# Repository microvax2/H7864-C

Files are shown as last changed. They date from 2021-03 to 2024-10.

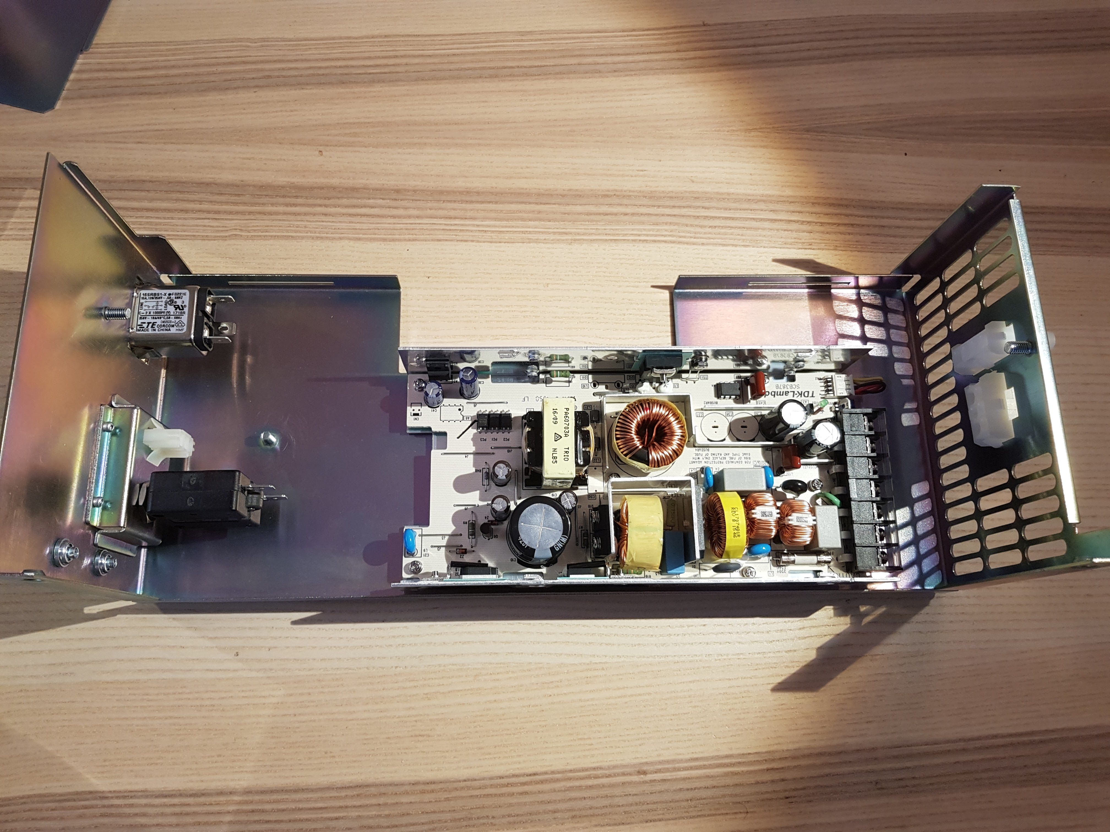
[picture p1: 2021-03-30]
Photos and Documents/H7864-C Before Wiring [1].jpg

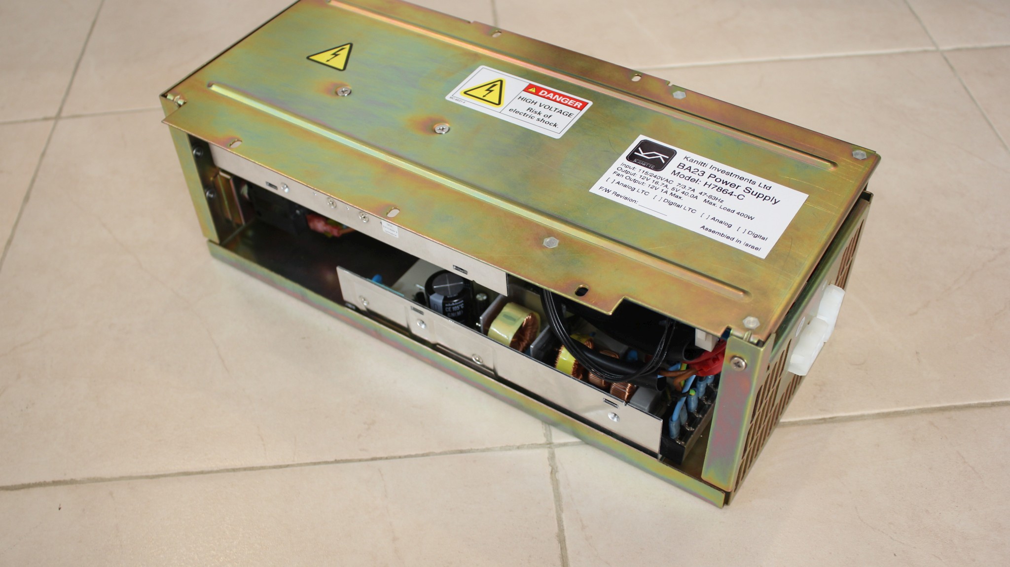
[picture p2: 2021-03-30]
Photos and Documents/H7864-C Assembled.jpg

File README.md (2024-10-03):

# H7864-C
A modern replacement for DEC's H7864-A/H7864-B (Astec AA12131)

Non-commercial license to do anything you want with the stuff in this repository.
For commecial licensing please contact me.

Project Folders:
Software - PIC12F675 firmware and sources

Metal Parts

Looms

PCB

Assembly

**IMPORTANT**

There are three "blocks" marked on the power supply control PCB.

A. A 74AC14 TTL gate - to generate POK, DCOK signals on power-up

B. An analog line monitoring circuitry that feeds the PIC microcontroller with a square wave signal and generates a "True" LTC clock

C. A PIC microcontroller - to generate POK, DCOK signals on power-up and an artificial LTC clock

Blocks A and C are mutually exclusive

Block B, if assembled together with Block C, enables the PIC to generate a correct sequence for POK, DCOK upon power-off.

**IMPORTANT** If assembling Block C (microcontroller) - don't populate the 74AC14 (U1).

Why this is important: ONLY OPTION B + C WILL PRESERVE THE TOY (Time of Year) CLOCK OF THE KA630.
This would probably be true for other KA6xx CPU Boards that keep time, boot parameters etc in battery-backed RAM.
The reason being, correct hardware shutdown must be performed by the CPU board upon power-off detection.

So your assembly options are:

**Option C: if you are lazy and don't care about preserving TOY clock after power-off, or have a PDP-11 and need an artificial LTC clock signal**

**Option A: if you are lazy, don't need an LTC clock, and don't even want to use a microcontroller**

**Option A+B: if you are lazy, have a PDP-11 system, and need a working, real LTC clock fed from mains**

**Option B+C: if you are lazy and want to keep the TOY clock functioning when power is removed**

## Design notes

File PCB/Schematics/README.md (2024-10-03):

Schematics for H7864-C

** READ THE COMMENTS ON SCHEMATIC SHEET 2 **
** ASSEMBLE ONLY ACCORDING TO THE OPTIONS YOU WANT **

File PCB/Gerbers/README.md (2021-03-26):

Gerber files for REV B PCB manufacturing

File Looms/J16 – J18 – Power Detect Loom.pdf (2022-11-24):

## J16 – J18 – Power Detect Loom

TE 52935 | TE 52935

120mm
AWG16-20

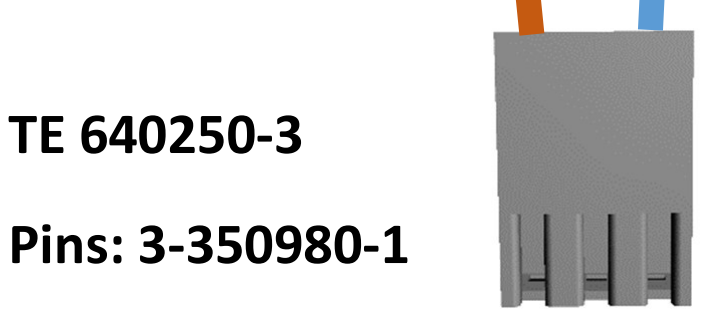
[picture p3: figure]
Pins: 3-350980-1

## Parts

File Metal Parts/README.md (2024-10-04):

Metalworks production files

**Important**
The files show a design plus two modifications (three holes moved and power entry cutout changed).
Make sure you account for those modifications.

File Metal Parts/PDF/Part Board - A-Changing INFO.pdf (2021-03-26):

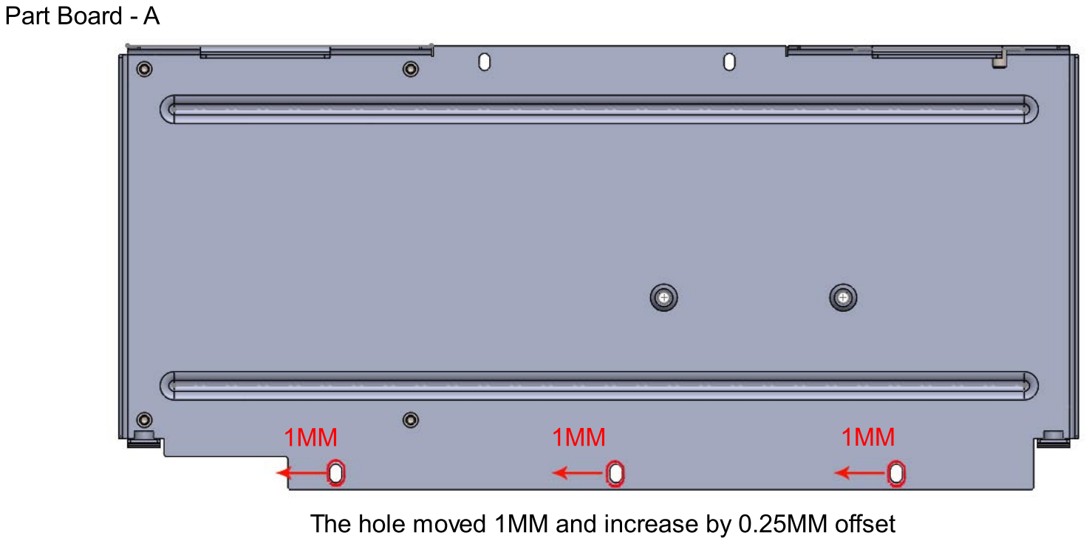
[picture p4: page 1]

Theholemoved1MMandincreaseby0.25MMoffset

PartBoard-A

1MM | 1MM | 1MM

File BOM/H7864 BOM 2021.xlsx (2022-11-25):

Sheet: Part List Report
 | Component list |  | Bill of Materials for PCB Document [H7864-B.pcbdoc]
 | Source Data From: |  | H7864-B.pcbdoc
 | Project: |  | H7864.PrjPcb
 | Variant: |  | Consult Schematic Sheet 2
 | Report Date: | 28/03/21 | 15:38
 | Print Date: | 2022-11-25 | 13:55:00
# | Designator | P/N | Description | Variant(S) (Consult Schematic Sheet 2) | Comment | Quantity
1 | C1 | TAJS106K006RNJ |  | A | 10uF | 1
2 | C2 | VJ0805Y103JXQPW1BC | Capacitor |  | VJ0805Y103JXAPW1BC | 1
3 | C3 | TCTAS0J107M8R |  | A | 100uF | 1
4 | C4 | B32642B6473J | Capacitor | B | 47nF 400VAC 15mm FILM | 1
5 | C5 | VJ0805Y104KXQCW1BC | Capacitor | C | VJ0805Y103JXAPW1BC | 1
6 | D1 | BAT54C | Schottky Barrier Double Diode | A | BAT54C | 1
7 | D2 | 1N4007 | 1 Amp General Purpose Rectifier |  | 1N4007 | 1
8 | D3 | 1N4007 | 1 Amp General Purpose Rectifier | B | 1N4007 | 1
9 | D4 | 1N4007 | 1 Amp General Purpose Rectifier |  | 1N4007 | 1
10 | D5 | SB130-T | 1 Amp General Purpose Rectifier |  | SB130-T | 1
11 | D6 | 1N4007 | 1 Amp General Purpose Rectifier | B | 1N4007 | 1
12 | D7 | BAT54C | Schottky Barrier Double Diode | C | BAT54C | 1
13 | F1 | 65600001009 | Fuse Holder 65600001009 + cover 65900000009 | B | Fuse holder, use 63mA fuse P/N 5ST 63-R | 1
14 | J9 | 640385-9 |  |  | 1-640385-9 | 1
15 | J14 | 640385-9 |  |  | 1-640385-9 | 1
16 | J15 | 640385-9 |  |  | 1-640385-9 | 1
17 | J16 | TE 640445-3 see note | Socket |  | Wire Solder | 1
18 | J17 |  | Socket |  | Remote On Off - | 1
19 | J18 | TE 640445-3 see note | Socket |  | Wire Solder | 1
20 | J19 | 640388-2 | Socket |  | Remote On Off + | 1
21 | LED1 | LTST-C170KRKT |  |  | LTST-C170KRKT | 1
22 | LED2 | LTST-C170KRKT |  |  | LTST-C170KRKT | 1
23 | LED3 | LTST-C170KRKT |  |  | LTST-C170TGKT | 1
24 | LED4 | LTST-C170KRKT |  |  | LTST-C170TGKT | 1
25 | MOV1 | 471KD10 | 10mm Disc Varistor | B | V10E300P, MOV-10D471K | 1
26 | P2 | 61300211121 | Header, 2-pin |  | Header/Jumper | 1
27 | P3 | B8B-PHDSS(LF)(SN) |  |  | B8B-PHDSS(LF)(SN) | 1
28 | P4 | 61300211121 | Header, 2-pin |  | Header/Jumper | 1
29 | P5 | B8B-PHDSS(LF)(SN) |  |  | B8B-PHDSS(LF)(SN) | 1
30 | P6 | 61300211121 | Header, 2-pin |  | Header/Jumper | 1
31 | P8 | 61300211121 | Header, 2-pin | C | Header/Jumper | 1
32 | Q1 | SI2306BDS-T1-E3 | N-Channel MOSFET |  | SI2306BDS-T1-E3 | 1
33 | Q2 | SI2306BDS-T1-E3 | N-Channel MOSFET |  | SI2306BDS-T1-E3 | 1
34 | Q3 | SI2306BDS-T1-E3 | N-Channel MOSFET |  | SI2306BDS-T1-E3 | 1
35 | R1 | CRCW080526K1FKEA | Resistor | A | 26.1K 1% | 1
36 | R2 | CRCW08051K00FKEAC | Resistor |  | 1K | 1
37 | R3 | CRCW0805180KFKEAC | Resistor | A | 180K 1% | 1
38 | R4 | CRCW080510K0JNEAC | Resistor | A | 10K | 1
39 | R5 | CRCW08051K00FKEAC | Resistor |  | 1K | 1
40 | R6 | CRCW0805180KFKEAC | Resistor | A | 180K 1% | 1
41 | R7 | CRCW0805330RFKEB | Resistor |  | 330 | 1
42 | R8 | MOS1CT528R223J | Resistor | B | 22K 1W TH | 1
43 | R9 | CRCW0805330RFKEB | Resistor |  | 330 | 1
44 | R10 | CRCW0805178RFKEA | Resistor |  | 178 | 1
45 | R11 | MOS1CT528R223J | Resistor | B | 22K 1W TH | 1
46 | R12 | CRCW080510K0JNEAC | Resistor | B | 10K | 1
47 | R13 | CRCW08050000Z0EC | Resistor |  | 0 | 1
48 | R14 | CRCW08052K00FKEAHP | Resistor |  | 2K | 1
49 | R15 | CRCW0805330RFKEB | Resistor |  | 330 | 1
50 | R16 | CRCW08050000Z0EC | Resistor |  | 0 | 1
51 | R17 | CRCW08051K00FKEAC | Resistor |  | 1K | 1
52 | R18 | CRCW0805383RFKEA | Resistor |  | 383 | 1
53 | R19 | CRCW08051K00FKEAC | Resistor |  | 1K | 1
54 | U1 | SN74HC14N | Hex Schmitt-Trigger Inverter | A, B | SN74AC14 | 1
55 | U2 | LTV816 | 4-Pin Phototransistor Optocoupler | B | LTV816 | 1
56 | U3 |  | FLASH-Based 8-Bit CMOS Microcontroller, 10-Bit A/D, 8-Pin PDIP, Industrial Temperature | C | PIC12F675-I/P | 1
Approved |  |  | Notes |  |  | 56
Note: J16-J18 can be populated with TE 640445-3, center pin must be removed. Orientation should match the wiring of loom J16-J18 for Live/Neutral connectios

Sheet: Project Information
Project Full Path | D:\GoogleDrive\VAX Museum\H7864\PCB Rev B\H7864.PrjPcb
Project Filename | H7864.PrjPcb
Variant Name | None
Data-Source Filename | H7864-B.pcbdoc
Data-Source Full Path | D:\GoogleDrive\VAX Museum\H7864\PCB Rev B\H7864-B.pcbdoc
Title | Bill of Materials for PCB Document [H7864-B.pcbdoc]
Total Quantity | 57
Report Time | 15:38
Report Date | 28/03/21
Report Date & Tine | 28/03/21 15:38
Output Name | Bill of Materials
Output Type | BOM_PartType
Output Generator Name | BOM
Output Generator Description | Bill of Materials

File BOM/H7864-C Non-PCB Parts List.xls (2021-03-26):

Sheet: Part List Report
 | Non-PCB Parts List
 | Source Data From:
 | Project: | H7864-C
 | Variant: | All Variants
 | Report Date:
 | Print Date:
# | Designator | Description | Supplier | Supplier p/n | Qty | Comment
1 | Metal Enclosure |  |  |  | 1
2 | Fan Cord | Qualtek 07145-24 | Mouser | 562-07145-24 | 1
5 | IEC Socket | TE Connectivity 15SRB1-Z | Mouser | 592-15SRB1-Z | 1
6 | Overload Switch- 5A | TE 1-1423364-2 | Mouser | 655-W57-XB1A4A10-5 | 1
7 | Overload Switch- 10A | TE 1-1423364-4 | Mouser | 655-1-1423364-4 (https://www.mouser.co.il/ProductDetail/TE-Connectivity-PB/1-1423364-4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) | 1
8 | Cable Tie | Cable tie, 100x2.5mm |  |  | 1
9 | LOOM1: Power |  |  |  | 7
10 | LOOM2: 5V + | 14AWG Red Solder to Fork 140mm | 76812.R8.03 (https://www.digikey.com/product-detail/en/general-cable-carol-brand/76812.R8.03/C76812R-50-ND/5452559) |  | 2
11 | LOOM3: 5V GND | 14AWG Black Solder to Fork 140mm | 76812.R8.01 |  | 2
12 | LOOM4: 12V + | 14AWG Red Solder to Fork 140mm | 76812.R8.03 (https://www.digikey.com/product-detail/en/general-cable-carol-brand/76812.R8.03/C76812R-50-ND/5452559) |  | 2
13 | LOOM5: 12V GND | 14AWG Black Solder to Fork 140mm | 76812.R8.01 |  | 2
14 | LOOM6: FRONT FAN |  |  |  | 1
15 | LOOM7: REMOTE |  |  |  | 1
16 | LOOM8: P/S | Hosuing + Jumper Pre-Crimped + Housing |  |  | 2
16 | LOOM8: Front PW | Hosuing + Jumper Pre-Crimped + Housing |  |  | 2
 | FAN | Modern replacement fan is Orion OD1238-12HTB |  | OD1238-12HTB

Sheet: Project Information
Project Full Path | W:\DIFT2\PCB Rev A\DIFT2.PrjPcb
Project Filename | DIFT2.PrjPcb
Variant Name | None
Data-Source Filename | DIFT2.PrjPcb
Data-Source Full Path | W:\DIFT2\PCB Rev A\DIFT2.PrjPcb
Title | <Parameter Title not found>
Total Quantity | 34
Report Time | 17:41:05
Report Date | 19/05/11
Report Date & Tine | 19/05/11 17:41:05
Output Name | Bill of Materials
Output Type | BOM_PartType
Output Generator Name | BOM
Output Generator Description | Bill of Materials

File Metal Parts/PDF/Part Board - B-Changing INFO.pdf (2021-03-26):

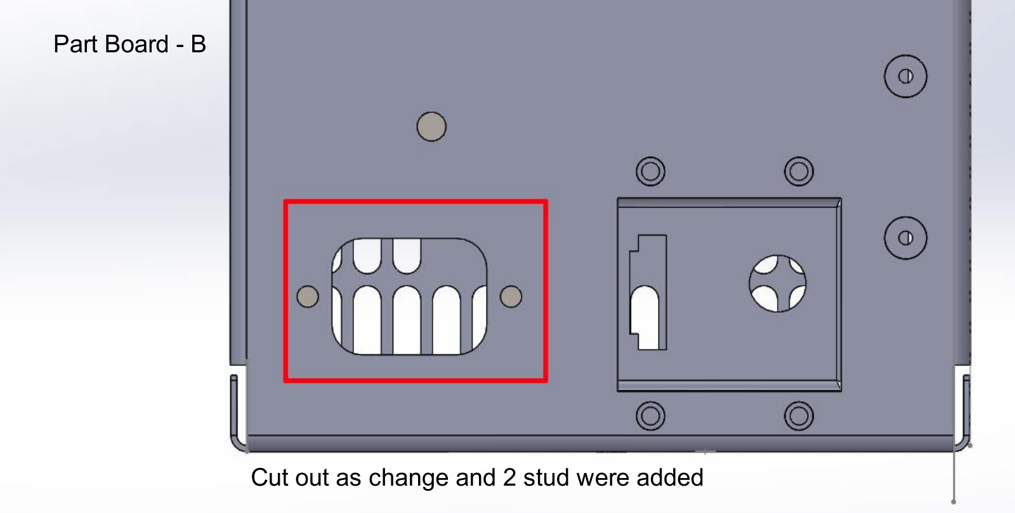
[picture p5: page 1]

PartBoard-B

Cutoutaschangeand2studwereadded

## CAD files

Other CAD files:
Metal Parts/XT/SB-20-7-17.x_t
Metal Parts/XT/SB.x_t
Metal Parts/XT/SUB Assem board A-18.09.17.x_t
Metal Parts/XT/SUB Assem board B-18.09.17.x_t

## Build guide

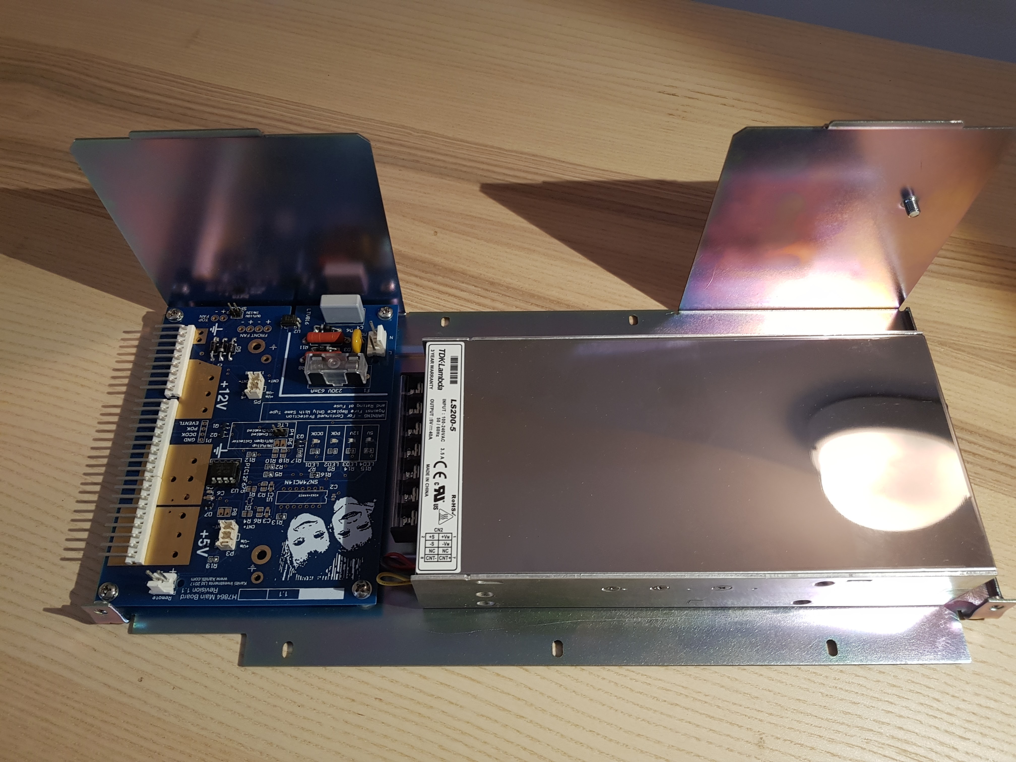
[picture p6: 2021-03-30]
Photos and Documents/H7864-C Before Wiring [2].jpg

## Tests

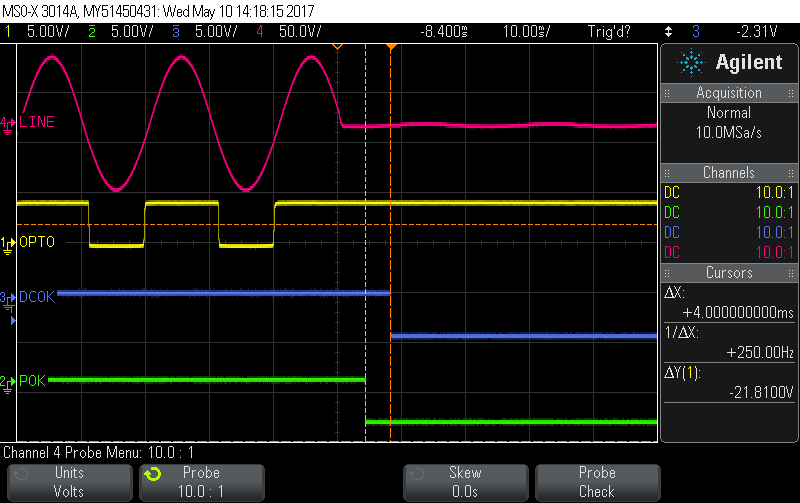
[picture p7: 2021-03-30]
Software Test Results/50HZEXP5 2017-05-10 09-41-35.png

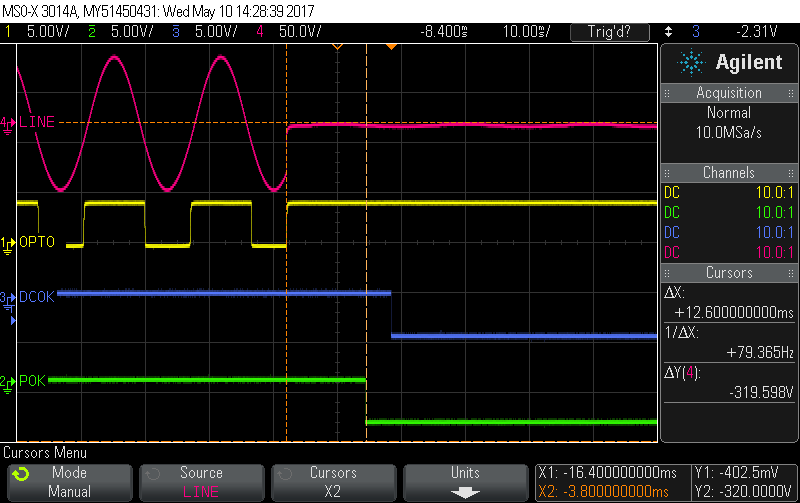
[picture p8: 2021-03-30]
Software Test Results/60HZEXP4 2017-05-10 09-51-53.png

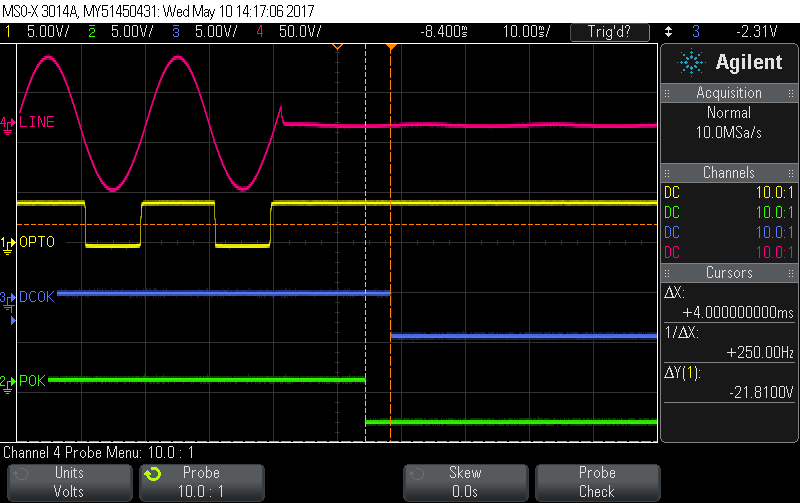
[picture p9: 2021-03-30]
Software Test Results/50HZEXP4 2017-05-10 09-40-23.png

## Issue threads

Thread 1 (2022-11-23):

Varistor alternative as well as part no. of mains connector

EarwainBanadar, 2022-11-23:
1. The varistor TVB7S471KR seems not to available anymore. Could you suggest and alternative?
     Not to forget that the TVB7S471KR is a SMD, not a disc type varistor.
3. The connector in the mains section in parallel to the varistor is not listed in the BOM. Of which partnumber is this connector?

microvax2, 2022-11-24:
1. Alternative varistors added to BOM: V10E300P, MOV-10D471K. Note that any 10mm 470V disc varistor will fit OK.
2. J16-J18 Part number added to BOM: TE 640446-3 with center pin removed
3. Added Loom "J16-J18 Power Detect", spade connectors on one side and TE 640250-3 on the other side, center pin unpopulated, two pins are 3-350980-1
4. Modified main AC wiring schematic to show connection of "J16-J18 Power Detect Loom", from live/neutral to main PCB.

EarwainBanadar, 2022-11-25:
I think there is a wrong PartNo. for item 54 in the PCB BOM.

SN74AHCT14D is a SMD type, would be SN74AC14N the correct one?

Closed 2023-01-06.

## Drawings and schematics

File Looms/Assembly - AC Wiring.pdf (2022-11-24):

LS200-5

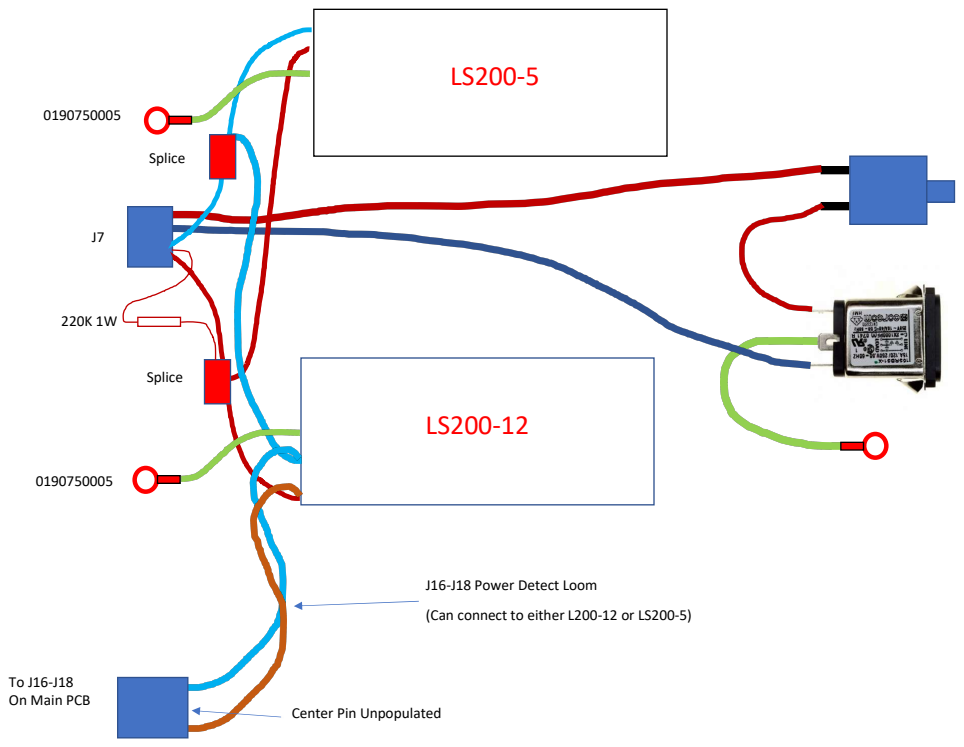
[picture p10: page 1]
Splice

J16-J18 Power Detect Loom
(Can connect to either L200-12 or LS200-5)

On Main PCB

Center Pin Unpopulated

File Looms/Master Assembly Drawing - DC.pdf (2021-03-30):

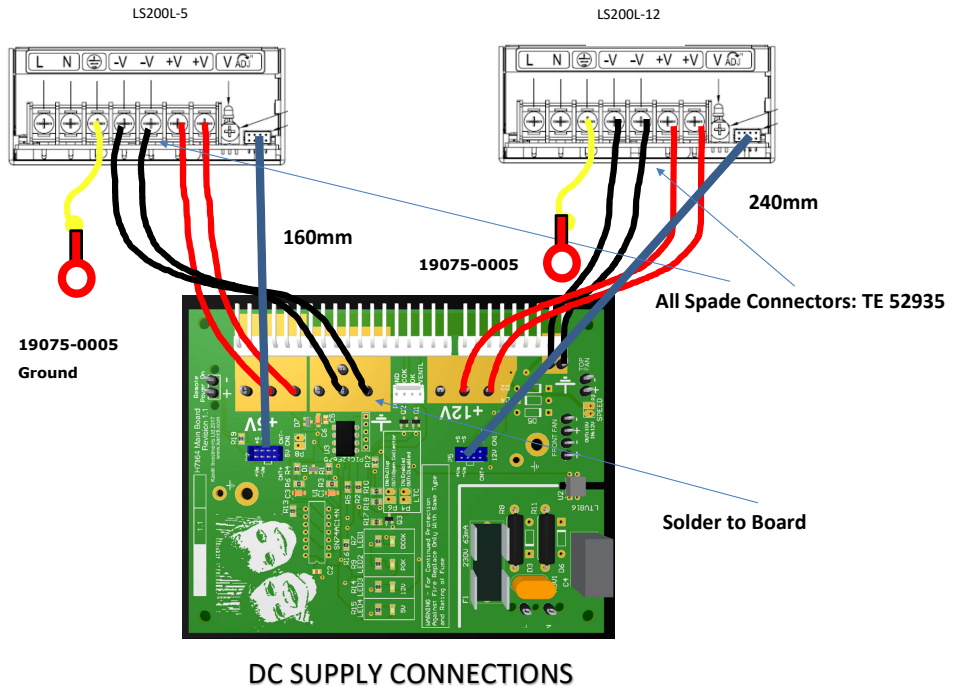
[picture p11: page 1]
Ground

All Spade Connectors: TE 52935

Solder to Board

DC SUPPLY CONNECTIONS

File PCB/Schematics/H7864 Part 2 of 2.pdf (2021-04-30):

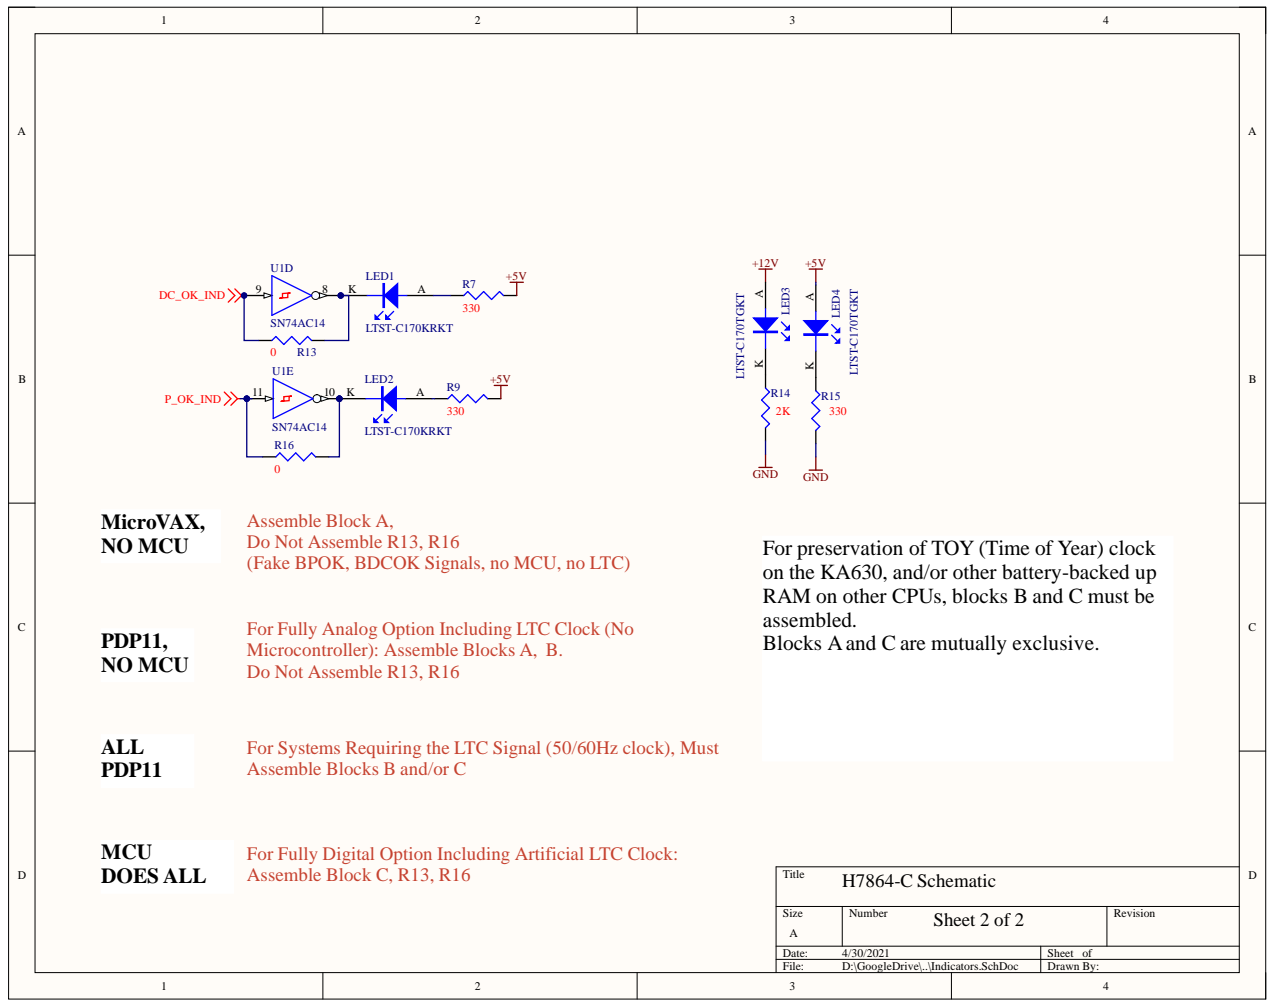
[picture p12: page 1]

Assemble Block A,
Do Not Assemble R1
(Fake BPOK, BDCOK Sig

For preservation of TOY (Time of
on the KA630, and/or other battery-backed up
RAM on other CPUs, blocks B and C must be
assembl
Blocks

A and C are mutually exclusive.

For Fully Digital Optio
Assemble Block C, R1

Size A | Nu m b er Sheet 2 of 2 | Revisio n

Date: 4/3 0/2 0 2 1 | Sheet o f
File: D:\Go o gleDrive\..\I n dicato rs.SchDo c | Drawn B y :

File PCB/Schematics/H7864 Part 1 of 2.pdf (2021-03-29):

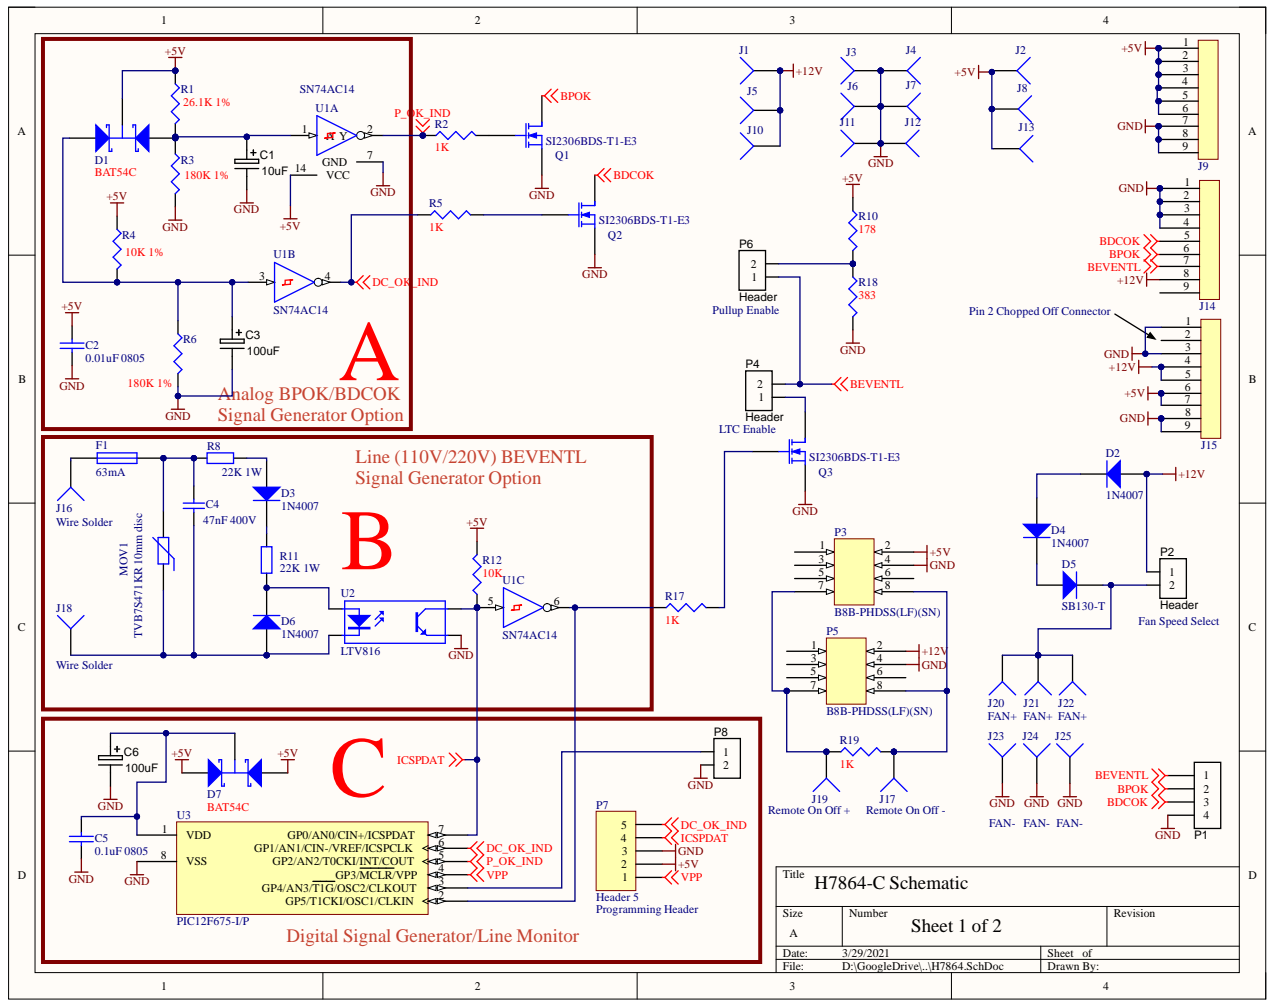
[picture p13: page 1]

Pin 2 Chopped Off Connector

Size A | Number Sheet 1 of 2 | Revision

Digital Signal Generator/Line Monitor

Date: 3/29/2021 | Sheet of
File: D:\GoogleDrive\..\H7864.SchDoc | Drawn By:

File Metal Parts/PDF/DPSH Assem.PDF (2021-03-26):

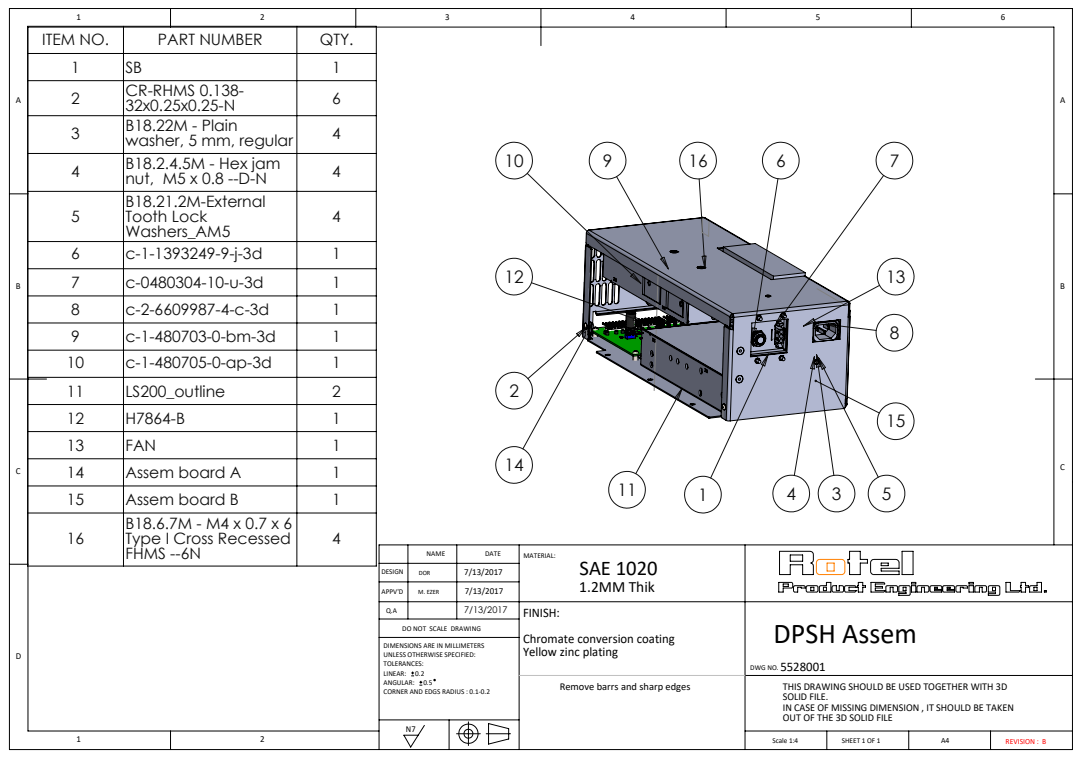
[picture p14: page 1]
SAE 1020 1.2MM Thik; REVISION : B; DPSH Assem; Scale 1:4; SHEET 1 OF 1; M. EZER

ITEM NO. | PART NUMBER | QTY.
1 | SB | 1
2 | CR-RHMS 0.138-32x0.25x0.25-N | 6
3 | B18.22M - Plain washer, 5 mm, regular | 4
4 | B18.2.4.5M - Hex jam nut, M5 x 0.8 --D-N | 4
5 | B18.21.2M-External Tooth Lock Washers_AM5 | 4

6 | c-1-1393249-9-j-3d | 1
7 | c-0480304-10-u-3d | 1
8 | c-2-6609987-4-c-3d | 1
9 | c-1-480703-0-bm-3d | 1
10 | c-1-480705-0-ap-3d | 1
11 | LS200_outline | 2
12 | H7864-B | 1
13 | FAN | 1
14 | Assem board A | 1
15 | Assem board B | 1
16 | B18.6.7M - M4 x 0.7 x 6 Type I Cross Recessed FHMS --6N | 4

DO NOT SCALE DRAWING
DIMENSIONS ARE IN MILLIMETERS
UNLESS OTHERWISE SPECIFIED:
TOLERANCES:
LINEAR: 0.2
ANGULAR: 0.5
CORNER AND EDGS RADIUS : 0.1-0.2

FINISH:
Chromate conversion coating
Yellow zinc plating

DWG NO. 5528001
THIS DRAWING SHOULD BE USED TOGETHER WITH 3D
SOLID FILE.
IN CASE OF MISSING DIMENSION , IT SHOULD BE TAKEN
OUT OF THE 3D SOLID FILE

Remove barrs and sharp edges

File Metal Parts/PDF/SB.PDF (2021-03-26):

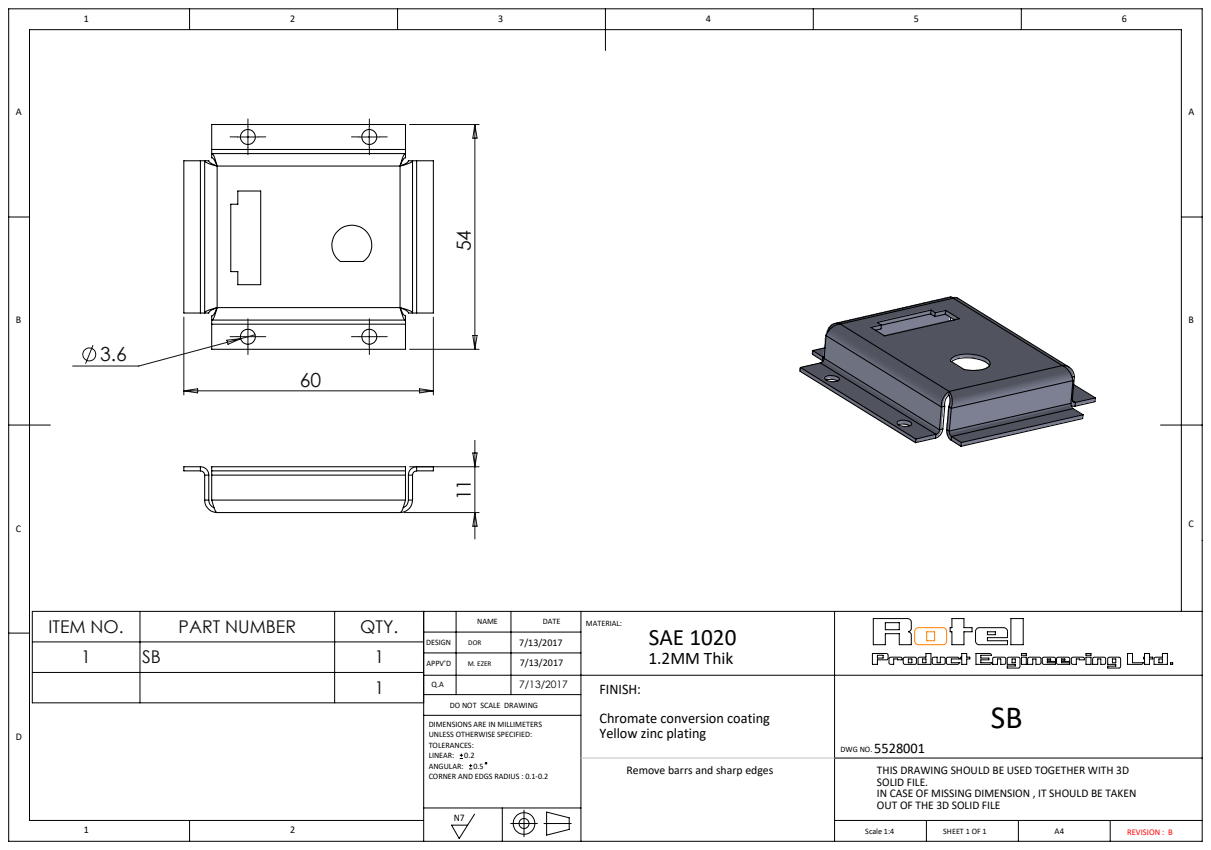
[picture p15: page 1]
REVISION : B; Scale 1:4; SHEET 1 OF 1; M. EZER

ITEM NO. | PART NUMBER | QTY.
1 | SB | 1

SAE 1020
1.2MM Thik
FINISH:
Chromate conversion coating
Yellow zinc plating

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

SB DWG NO. 5528001

Remove barrs and sharp edges

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

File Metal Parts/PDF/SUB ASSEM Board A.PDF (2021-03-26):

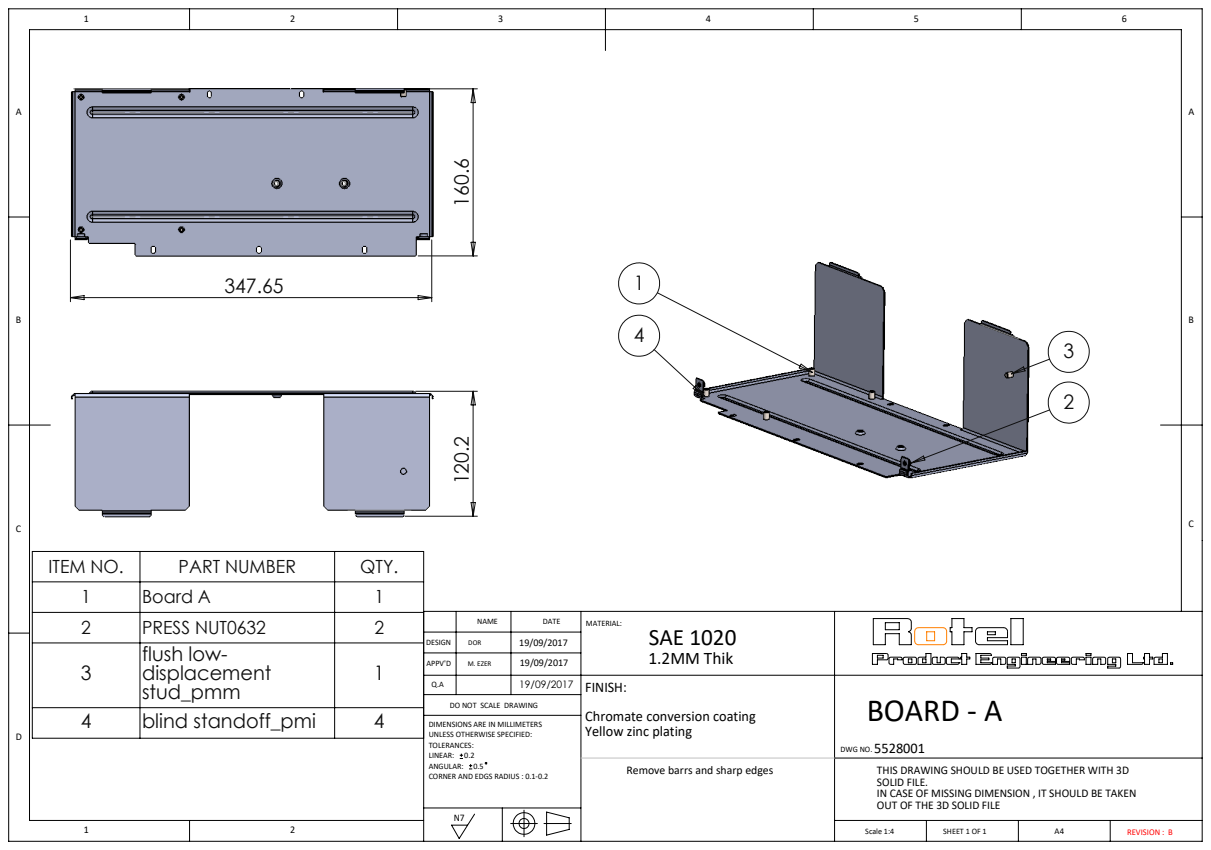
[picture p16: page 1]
SAE 1020 1.2MM Thik; REVISION : B; BOARD - A; Scale 1:4; SHEET 1 OF 1; M. EZER

ITEM NO. | PART NUMBER | QTY.
1 | Board A | 1
2 | PRESS NUT0632 | 2
3 | flush low-displacement stud_pmm | 1

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

FINISH:
Chromate conversion coating
Yellow zinc plating

4 | blind standoff_pmi | 4

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

Remove barrs and sharp edges

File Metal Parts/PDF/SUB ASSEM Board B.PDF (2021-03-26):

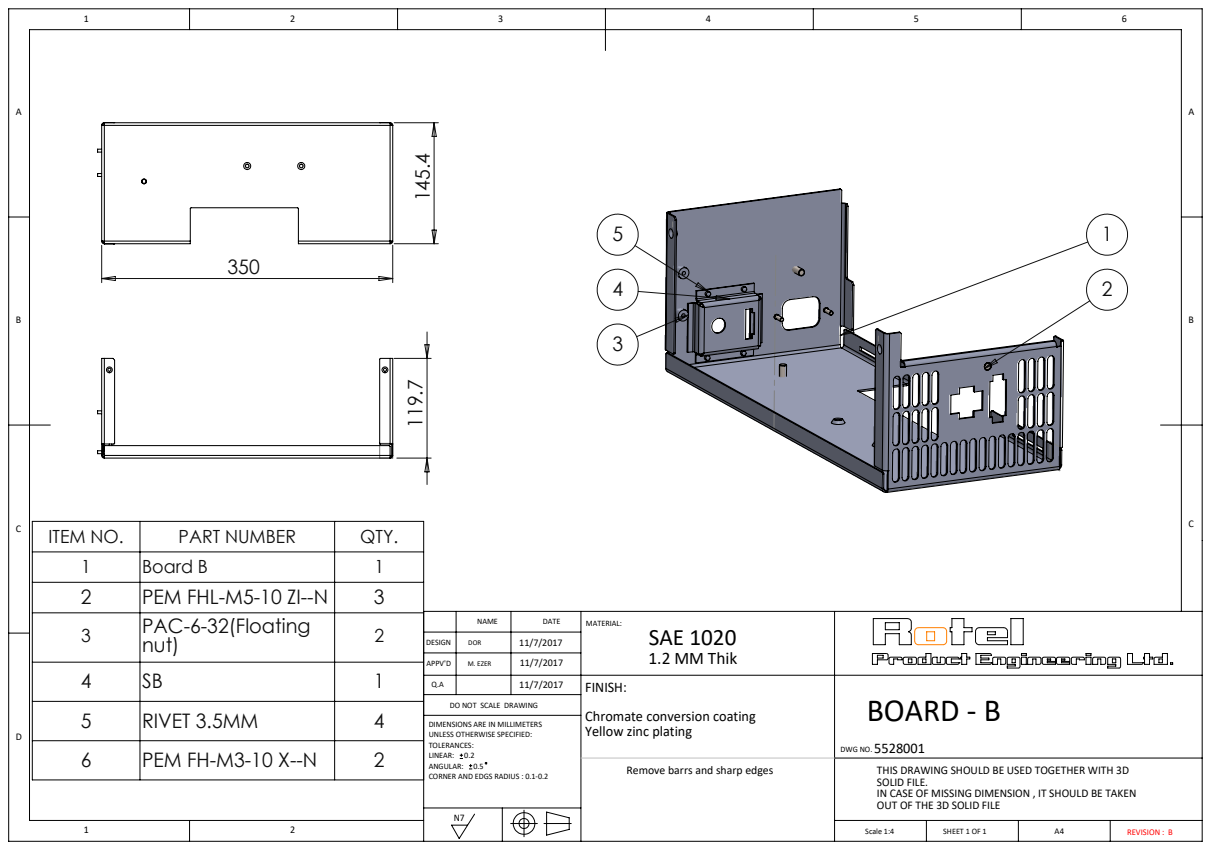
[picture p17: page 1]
SAE 1020 1.2 MM Thik; REVISION : B; BOARD - B; Scale 1:4; SHEET 1 OF 1; M. EZER

ITEM NO. | PART NUMBER | QTY.
1 | Board B | 1
2 | PEM FHL-M5-10 ZI--N | 3
3 | PAC-6-32(Floating nut) | 2

4 | SB | 1
5 | RIVET 3.5MM | 4
6 | PEM FH-M3-10 X--N | 2

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

FINISH:
Chromate conversion coating
Yellow zinc plating

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

Remove barrs and sharp edges

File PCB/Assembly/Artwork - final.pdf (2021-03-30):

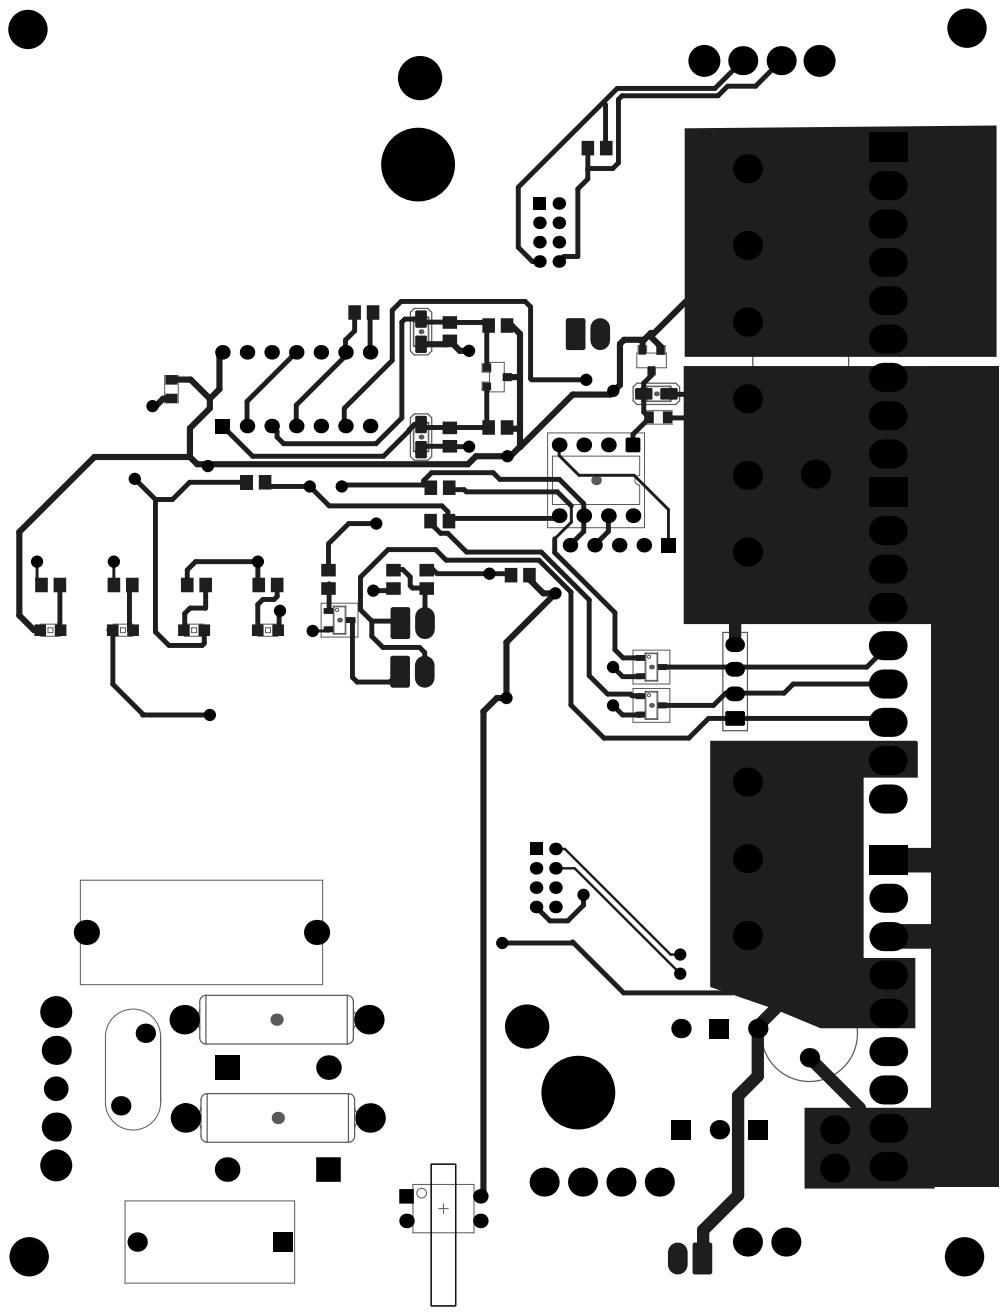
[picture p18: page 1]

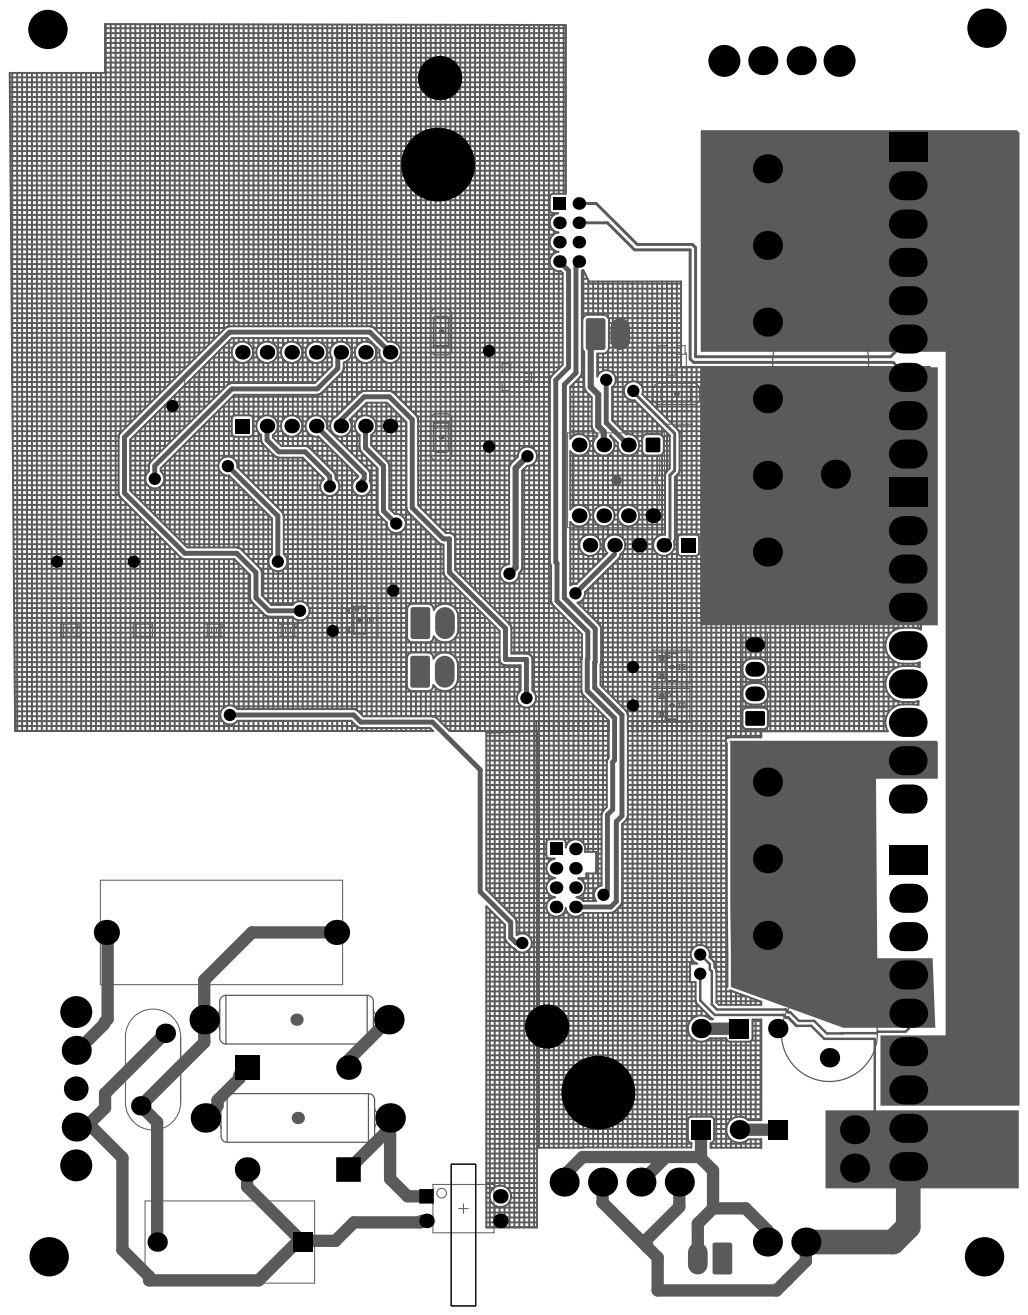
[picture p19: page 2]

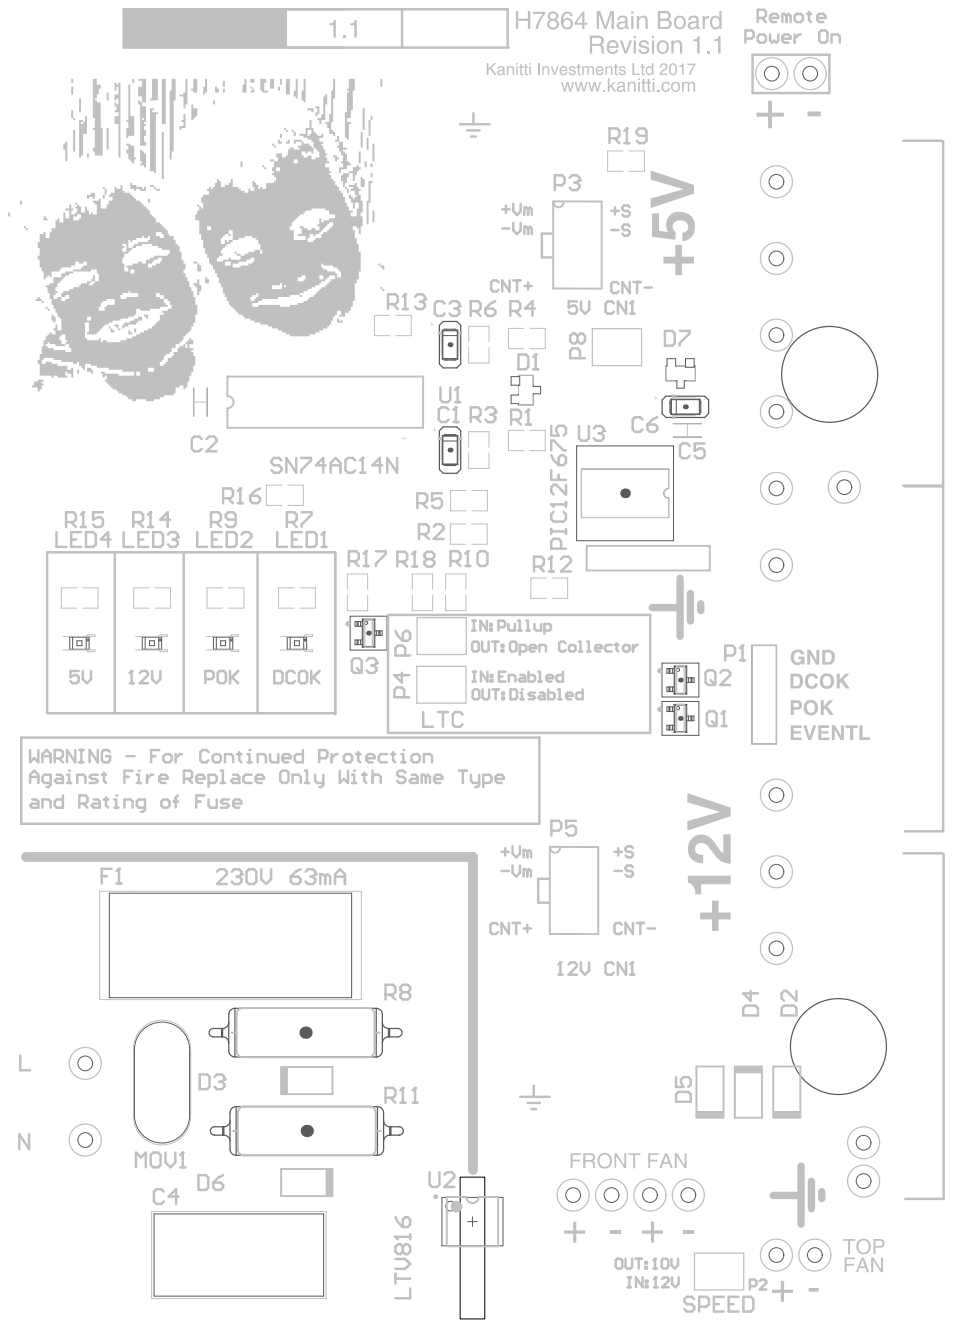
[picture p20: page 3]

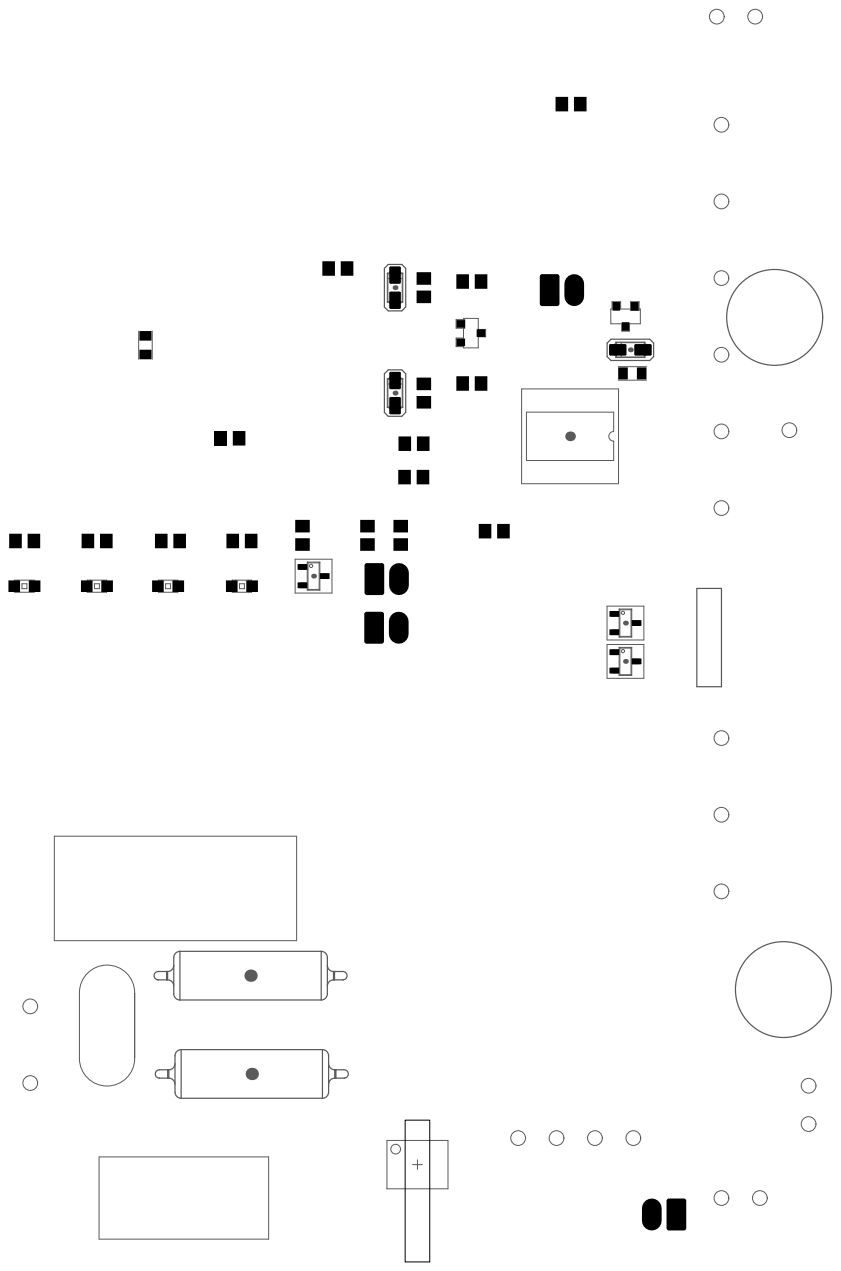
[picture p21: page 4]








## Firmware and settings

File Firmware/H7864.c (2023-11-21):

/*
 * H7864 Software
 * 
 * PIC12F675
 */

// XC8 header:
#include <xc.h>
//__CONFIG(0x005c);
#pragma config FOSC = 4
#pragma config WDTE = 1
#pragma config PWRTE = 1
#pragma config MCLRE = 0
#pragma config BOREN = 1

// HTPICC Header:
//#include <htc.h>
//#include <PIC12F675.H>
//__CONFIG(0x005c);
        


#define OPTION_MASK 	0b11000111
#define WDT_PRESCALER 	0b00001000

#define LINE_CLOCK GPIO0 // optocpoupler; provides 50Hz or 60Hz, if circuit is present and working
#define BPOK GPIO2       // POK signal to the QBUS; '1' forces an open collector to ground
#define BDCOK GPIO1      // DCOK signal to the QBUS; '1' forces an open collector to ground
#define BEVENTL GPIO5    // LINE CLOCK to the QBUS; used by PDP11 systems; open collector output
void init(void)
{
	ANSEL=0;
	CMCON=0x07;
	TRISIO = 0b00011001;   
    BPOK=1;
    BDCOK=1;
	T1CON=0x30; 
    TMR1IE=1;
    PEIE=1;
    WPU=0;
    OPTION_REG = OPTION_MASK | WDT_PRESCALER; //WDT has prescaler
}
#define RESET_TIME clock=0;clock=0;
char clock; 
char limit;
static bit safe_mode;
static void interrupt isr( void)
{
  TMR1IF=0;
  TMR1L=-123;
  TMR1H=0xff;
  clock++;
}
void identify_line_freq(void)
{
  static bit b;
  char i=0;
  char cnt_50=0;
 
  // detect a change on LINE_CLOCK input, otherwise go to safe mode operation
  // repeat twice, so we do not detect a glitch as a signal
  for (i=0; i<=1; i++)
    { b = LINE_CLOCK;
      RESET_TIME;
      while (b==LINE_CLOCK)
        {  
             CLRWDT(); 
             if (clock>=200) 
               { safe_mode=1;
                 return;
               }
            }
    }
  RESET_TIME;
  while (i<11)
    {      
      RESET_TIME;
      while (!LINE_CLOCK) CLRWDT();
      while (LINE_CLOCK) CLRWDT();
      if (clock>=18) cnt_50++;       
      i++;
    }
  if (cnt_50>8) limit=15; else limit=13;
}

void main( void)
{
    char i;
    static bit b;
    init();
   
    GIE=1;    
    TMR1H=0xff;
    TMR1L=-125;
    TMR1IF=0;
    TMR1ON=1;
    safe_mode=0;
    // test line frequency, if no signal at all - raise the safe_mode flag
    identify_line_freq();
   
    while (1)
      {
        /*
                            POWER - ON RESET SEQUENCE         
         */
         RESET_TIME;
         while (clock<=3) CLRWDT();    //3ms minimum from P/U, send DCOK
         BDCOK=0;
         RESET_TIME;
         while(clock<100) CLRWDT();    // then after 100ms, send POK
         BPOK=0; 
         // NO AC SIGNAL: "SAFE MODE"  IS JUST 50HZ GENERATION UNTIL POWER OFF
         while (safe_mode)
           { 
             RESET_TIME;
             while(clock<10) CLRWDT(); 
             BEVENTL=!BEVENTL;             
           }
         // ELSE
         // NORMAL OPERATION, GENERATE 50/60HZ BASED ON THE LINE INPUT
         // AND DETECT A POWER FAULT AND RESPOND ACCORDINGLY
         while (!BPOK)
          {
              b = !b;   
              BEVENTL=!BEVENTL; // generate a fake 50H in sync with the real 50hz
              RESET_TIME;
              while (LINE_CLOCK==b) 
              {
                CLRWDT();
                if (clock>=limit)
                  { BPOK=1; 
                  break;}
               }
          }
        //execution ends up here if a 50Hz edge is missing for more than the allowed max. time
        // the loop above already negated POK, now continue:        
        RESET_TIME;
        while (clock<4) CLRWDT();
        // at this point, the obligatory 4ms has passed
        BDCOK=1;
        RESET_TIME;
        while (clock<1) CLRWDT();
        // at this point, power down has been completed
        // option 1: GLITCH
        // in this case, continue following the line input for 1 second,
        // with POK and DCOK showing failed power. Then, start the main loop again for a new reset sequence etc
        // option 2: A REAL POWER FAILURE        
        // in this case, execution may or may not complete the following code,
        // the on-board capacitor has enough charge to keep us going for a few more ms, that's it
        for (i=0; i<=25; i++)
          {
           while (!LINE_CLOCK) CLRWDT();      
           while (LINE_CLOCK) CLRWDT();
          }
        // finished the orderly shutdown, if power is still on then a new RESET sequence follows:
      }
  
}

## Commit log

2021-03-27 Create BOM
2022-11-24 Added Varistor Alternate P/N, J16-J18 P/N
    [H7864 BOM 2021.xlsx]
2022-11-25 Add files via upload
    Corrected U1 P/N to SN74HC14N / SN74AC14
    [H7864 BOM 2021.xlsx]
